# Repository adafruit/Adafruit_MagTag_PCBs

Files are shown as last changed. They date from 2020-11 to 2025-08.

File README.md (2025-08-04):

## Adafruit MagTag PCB

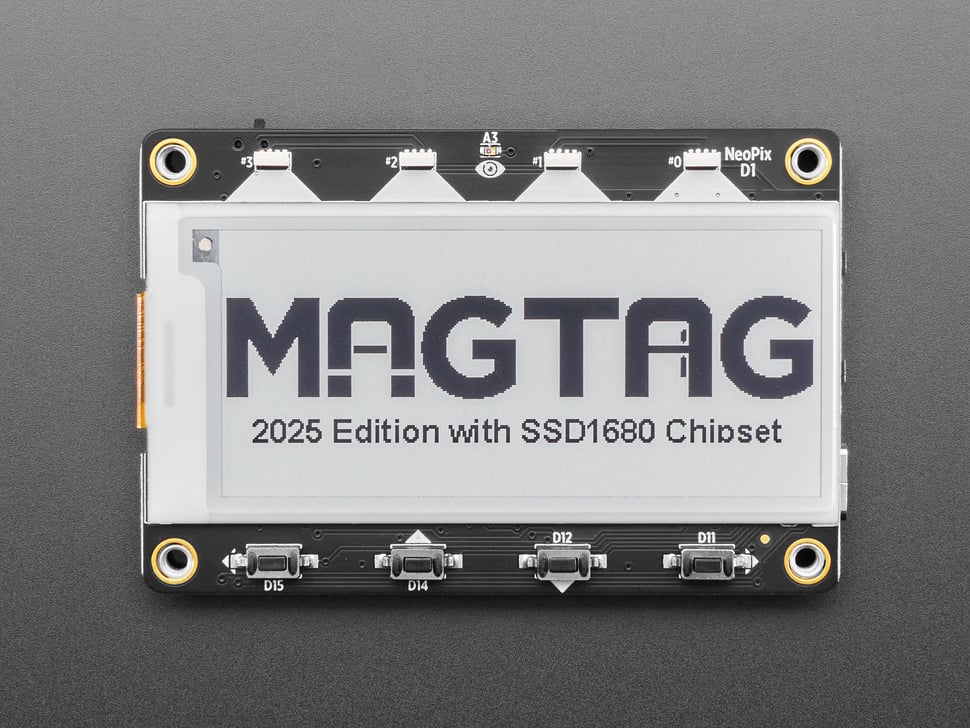
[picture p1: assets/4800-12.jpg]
<a href="http://www.adafruit.com/products/4800"><br/>
Click here to purchase one from the Adafruit shop</a>

PCB files for the Adafruit MagTag.

Format is EagleCAD schematic and board layout
* https://www.adafruit.com/product/4800

### Description

The Adafruit MagTag combines the new ESP32-S2 wireless module and a 2.9" grayscale E-Ink display to make a low-power IoT display that can show data on its screen even when power is removed! The ESP32-S2 is great because it builds on the years of code and support for the ESP32 and also adds native USB support so you can use this board with Arduino or CircuitPython!

New for 2025! After a long break, the MagTag is back in stock, we've found a 2.9" grayscale E-Ink display that replaces the old discontinued ILI0373. The new display has an SSD1680 chip driver and is supported in Arduino and CircuitPython version 10+!

We designed this board to be low-power friendly - with a spot for a 350 or 420 mAh battery and built in battery charging over USB C. During deep sleep, with the NeoPixels and speaker amplifier disabled, we measured 250uA power draw so you can run for a few weeks between charges.

And of course, the Mag in MagTag stands for magnetic. We have four M3 standoffs that will work perfectly with these mini magnet feet. (Originally they're designed for RGB Matrices but they'll do an excellent job here as well). Screw on the feet and you can attach this display to a metallic shelf, fridge, or bench.

Here's the cool hardware we put together:

* ESP32-S2 240MHz Tensilica processor - the next generation of ESP32, now with native USB so it can act like a keyboard/mouse, MIDI device, disk drive, etc!
* WROVER module has FCC/CE certification and comes with 4 MByte of Flash and 2 MByte of PSRAM - you can have huge data buffers
* 2.9" grayscale display with 296x128 pixels. Each pixel can be white, light gray, dark gray or black. Compared to 'tri-color' displays with a red pigment, this display takes a lot less time to update, only about a second instead of 15 seconds!
* USB C power and data connector
* Four RGB side-emitting NeoPixels so you can light up the display with any color or pattern
* Four buttons can be used to wake up the ESP32 from deep-sleep, or select different modes
* Triple-axis accelerometer (LIS3DH) can be used to detect orientation of the display
* Speaker/Buzzer with mini class D amplifier on DAC output A0 can play tones or lo-fi audio clips.
* Front facing light sensor
* STEMMA QT port for attaching all sorts of I2C devices
* Two STEMMA 3 pin JST connectors for attaching NeoPixels, speakers, servos or relays.
* On/Off switch
* Boot and Reset buttons for re-programming

Revision History:

* As of July 22, 2025 – The display has been updated (old one discontinued); it now uses a modern SSD1680 chip instead of the discontinued ILI0373 - we have support in CircuitPython/Python/Arduino for it!
* As of June 17, 2022 - This board may come with a different regulator than AP2112K due to parts shortages. The regulator can provide at least 500mA.
* As of Dec 14, 2020 we're shipping with a different front silkscreen (black not white) Product is otherwise the same

### License

Adafruit invests time and resources providing this open source design, please support Adafruit and open-source hardware by purchasing products from [Adafruit](https://www.adafruit.com)!

Designed by Limor Fried/Ladyada for Adafruit Industries.

Creative Commons Attribution/Share-Alike, all text above must be included in any redistribution.
See license.txt for additional details.

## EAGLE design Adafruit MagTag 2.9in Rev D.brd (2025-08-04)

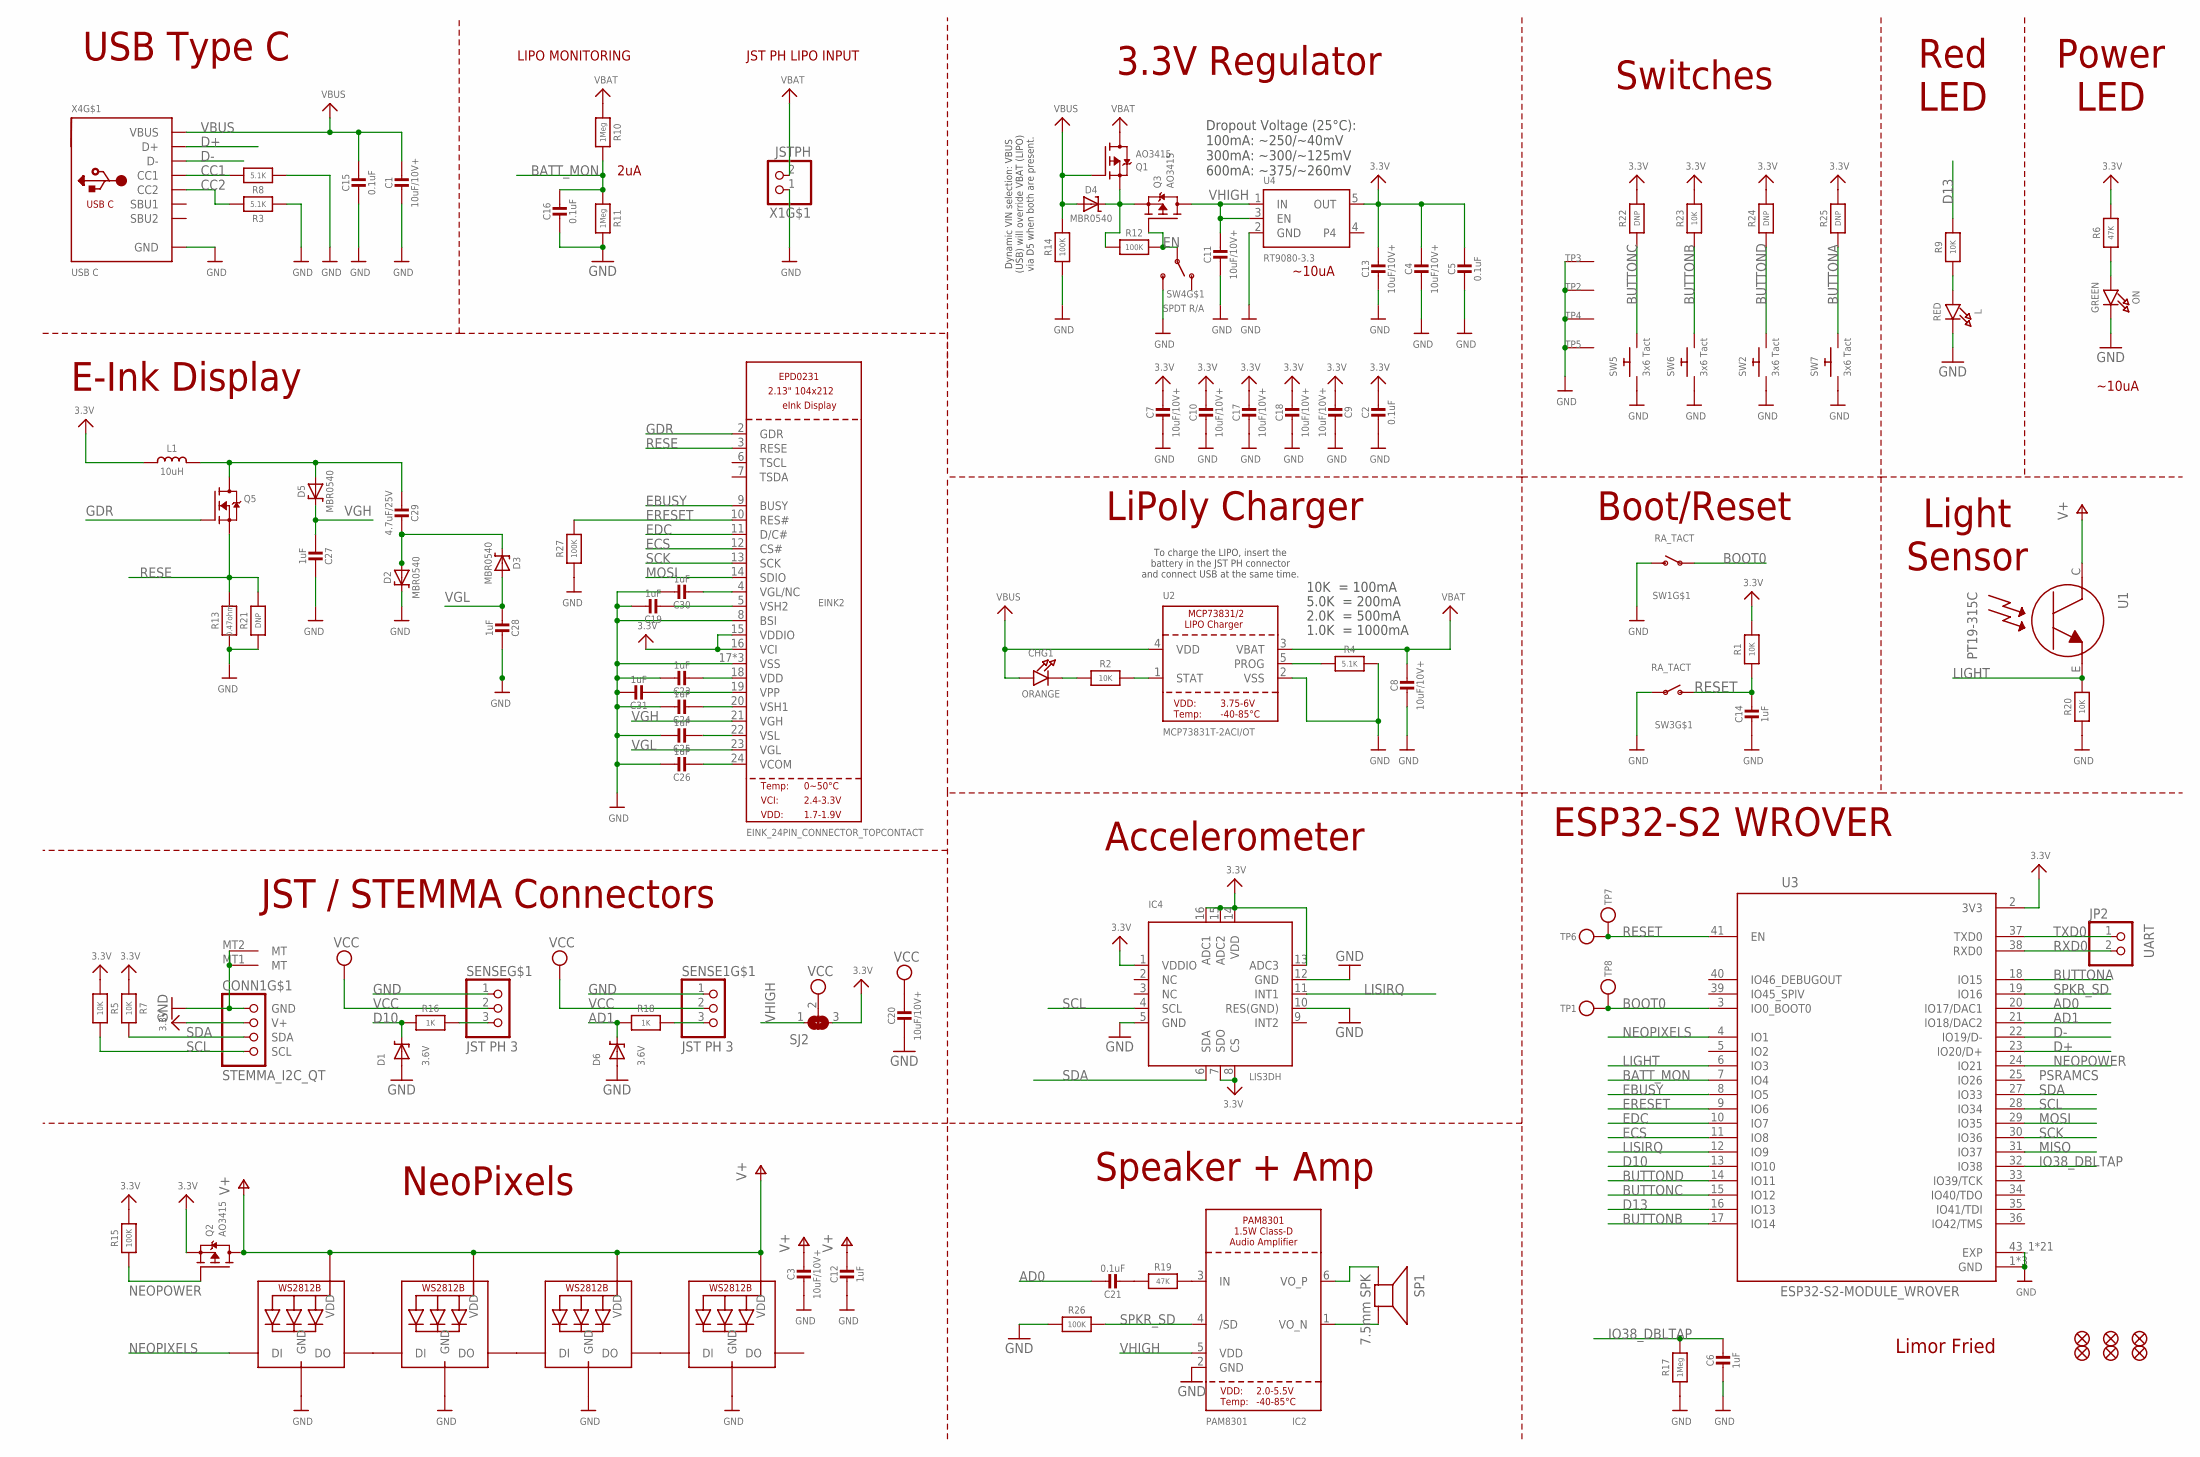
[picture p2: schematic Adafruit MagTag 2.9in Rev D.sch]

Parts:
C1, C3, C4, C7, C8, C9, C10, C11, C13, C17, C18, C20: 10uF/10V+; 0805-NO
C2, C5, C15, C16, C21: 0.1uF; 0603-NO
C6, C12, C14: 1uF; 0603-NO
C19, C23, C24, C25, C26, C27, C28, C30, C31: 1uF; 0805-NO
C29: 4.7uF/25V; 0805-NO
CHG1: ORANGE; CHIPLED_0603_NOOUTLINE
CONN1: STEMMA_I2C_QT; JST_SH4
D1, D6: 3.6V; SOD-323
D2, D3, D4, D5: MBR0540; SOD-123
EINK2: EINK_24PIN_CONNECTOR_TOPCONTACT; EINK_24PIN_TOPCONTACT
FID1, FID2, FID3, FID4, FID5, FID6: FIDUCIAL_1MM
IC2: PAM8301; SOT23-6
IC4: LIS3DH; LGA16_3X3MM
JP2: UART; 1X02_ROUND
L: RED; CHIPLED_0603_NOOUTLINE
L1: 10uH; INDUCTOR_4X4MM_NR401
LED2, LED3, LED4, LED5: WS2812B_4020
ON: GREEN; CHIPLED_0603_NOOUTLINE
Q1, Q2, Q3: AO3415; SOT23-R
Q5: IRLML0100; SOT23-3
R1, R2, R5, R7, R9, R20, R23: 10K; 0603-NO
R3, R4, R8: 5.1K; 0603-NO
R6, R19: 47K; 0603-NO
R10, R11, R17: 1Meg; 0603-NO
R12, R14, R15, R26, R27: 100K; 0603-NO
R13: 0.47ohm; 0805_10MGAP
R16, R18: 1K; 0603-NO
R21: DNP; 0805_10MGAP
R22, R24, R25: DNP; 0603-NO
SENSE, SENSE1: JST PH 3; JSTPH3
SJ2: SOLDERJUMPER_2WAY; SOLDERJUMPER_2WAY_OPEN_NOPASTE
SP1: 7.5mm SPK; BUZZER_SMT_7.5MM
SW1, SW3: RA_TACT; SPST_TACTILE_RA
SW2, SW5, SW6, SW7: 3x6 Tact; TACTILE_3X6MM
SW4: SPDT R/A; SPDT_SMT_SSSS811101
TP1, TP6, TP7, TP8: TESTPOINTROUND1.5MMNO; TESTPOINT_ROUND_1.5MM_NO
TP2, TP3, TP4, TP5: SEWTAP_SMTNUTM3; SMT_NUT_3MM
U1: PT19-315C; ALS-PT19-315C
U2: MCP73831T-2ACI/OT; SOT23-5
U3: ESP32-S2-MODULE_WROVER; MODULE_ESP32-S2-WROVER
U4: RT9080-3.3; SOT23-5; JLC_ROTATION 0
X1: JSTPH; JSTPH2_BATT
X4: USB C; USB_C_CUSB31-CFM2AX-01-X

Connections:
3.3V: C2.1, C4.1, C5.1, C7.1, C9.2, C10.1, C13.1, C17.1, C18.1, CONN1.2 (V+), EINK2.15 (VDDIO), EINK2.16 (VCI), IC4.1 (VDDIO), IC4.7 (SDO), IC4.8 (CS), IC4.13 (ADC3), IC4.14 (VDD), IC4.15 (ADC2), IC4.16 (ADC1), L1.P$2 (2), Q2.2 (S), R1.2, R5.1, R6.2, R7.1, R15.2, R22.2, R23.2, R24.2, R25.2, SJ2.3, U3.2 (3V3), U4.5 (OUT)
A1_JST1: R18.1, SENSE1.3
AD0: C21.1, U3.20 (IO17/DAC1)
AD1: D6.C, R18.2, U3.21 (IO18/DAC2)
BATT_MON: C16.1, R10.2, R11.1, U3.7 (IO4)
BOOT0: SW1.1, TP1.P$1, TP8.P$1, U3.3 (IO0_BOOT0)
BUTTONA: R25.1, SW7.P$2, U3.18 (IO15)
BUTTONB: R23.1, SW6.P$2, U3.17 (IO14)
BUTTONC: R22.1, SW5.P$2, U3.15 (IO12)
BUTTOND: R24.1, SW2.P$2, U3.14 (IO11)
CC1: R8.2, X4.A5 (CC1)
CC2: R3.2, X4.B5 (CC2)
D10: D1.C, R16.2, U3.13 (IO10)
D10_JST: R16.1, SENSE.3
D13: R9.2, U3.16 (IO13)
D+: U3.23 (IO20/D+), X4.A6 (D+), X4.B6 (D+)
D-: U3.22 (IO19/D-), X4.A7 (D-), X4.B7 (D-)
EBUSY: EINK2.9 (BUSY), U3.8 (IO5)
ECS: EINK2.12 (CS#), U3.11 (IO8)
EDC: EINK2.11 (D/C#), U3.10 (IO7)
EN: Q3.1 (G), R12.2, SW4.B
ERESET: EINK2.10 (RES#), R27.2, U3.9 (IO6)
GDR: EINK2.2 (GDR), Q5.1 (G)
GND: C1.2, C2.2, C3.2, C4.2, C5.2, C6.2, C7.2, C8.2, C9.1, C10.2, C11.2, C12.2, C13.2, C14.2, C15.2, C16.2, C17.2, C18.2, C19.1, C20.2, C23.1, C24.1, C25.1, C26.1, C27.2, C28.2, C30.1, C31.1, CONN1.1 (GND), CONN1.MT1 (MT), CONN1.MT2 (MT), D1.A, D2.C, D6.A, EINK2.8 (BSI), EINK2.17 (VSS), EINK2.SPRT1 (VSS), EINK2.SPRT2 (VSS), IC2.2 (GND), IC4.5 (GND), IC4.10 (RES(GND)), IC4.12 (GND), L.C, LED2.4 (GND), LED3.4 (GND), LED4.4 (GND), LED5.4 (GND), ON.C, R3.1, R4.2, R8.1, R11.2, R13.2, R14.1, R17.1, R20.1, R21.2, R26.1, R27.1, SENSE.1, SENSE1.1, SW1.2 (S), SW2.P$1, SW3.1, SW4.C (S), SW5.P$1, SW6.P$1, SW7.P$1, TP2.P$1, TP3.P$1, TP4.P$1, TP5.P$1, U2.2 (VSS), U3.1 (GND), U3.26 (GND), U3.42 (GND), U3.43_1 (EXP), U3.43_2 (EXP), U3.43_3 (EXP), U3.43_4 (EXP), U3.43_5 (EXP), U3.43_6 (EXP), U3.43_7 (EXP), U3.43_8 (EXP), U3.43_9 (EXP), U3.43_10 (EXP), U3.43_11 (EXP), U3.43_12 (EXP), U3.43_13 (EXP), U3.43_14 (EXP), U3.43_15 (EXP), U3.43_16 (EXP), U3.43_17 (EXP), U3.43_18 (EXP), U3.43_19 (EXP), U3.43_20 (EXP), U3.43_21 (EXP), U4.2 (GND), X1.1, X4.A1B12 (GND), X4.B1A12 (GND)
IO38_DBLTAP: C6.1, R17.2, U3.32 (IO38)
LIGHT: R20.2, U1.E, U3.6 (IO3)
LISIRQ: IC4.11 (INT1), U3.12 (IO9)
MISO: U3.31 (IO37)
MOSI: EINK2.14 (SDIO), U3.29 (IO35)
unnamed: L.A, R9.1
unnamed: LED2.3 (DO), LED3.1 (DI)
unnamed: ON.A, R6.1
unnamed: CHG1.C, R2.1
unnamed: C21.2, R19.1
unnamed: R2.2, U2.1 (STAT)
unnamed: IC2.3 (IN), R19.2
unnamed: R4.1, U2.5 (PROG)
unnamed: C19.2, EINK2.5 (VSH2)
unnamed: C23.2, EINK2.18 (VDD)
unnamed: C24.2, EINK2.20 (VSH1)
unnamed: LED4.3 (DO), LED5.1 (DI)
unnamed: C29.2, D2.A, D3.C
unnamed: C29.1, D5.A, L1.P$1 (1), Q5.3 (D)
unnamed: C30.2, EINK2.4 (VGL/NC)
unnamed: C31.2, EINK2.19 (VPP)
unnamed: LED3.3 (DO), LED4.1 (DI)
unnamed: IC2.1 (VO_N), SP1.-
unnamed: IC2.6 (VO_P), SP1.+
unnamed: D4.C, Q1.2 (S), Q3.2 (S), R12.1
unnamed: C25.2, EINK2.22 (VSL)
unnamed: C26.2, EINK2.24 (VCOM)
NEOPIXELS: LED2.1 (DI), U3.4 (IO1)
NEOPOWER: Q2.1 (G), R15.1, U3.24 (IO21)
RESE: EINK2.3 (RESE), Q5.2 (S), R13.1, R21.1
RESET: C14.1, R1.1, SW3.2 (S), TP6.P$1, TP7.P$1, U3.41 (EN)
RXD0: JP2.2, U3.38 (RXD0)
SCK: EINK2.13 (SCK), U3.30 (IO36)
SCL: CONN1.4 (SCL), IC4.4 (SCL), R5.2, U3.28 (IO34)
SDA: CONN1.3 (SDA), IC4.6 (SDA), R7.2, U3.27 (IO33)
SPKR_SD: IC2.4 (/SD), R26.2, U3.19 (IO16)
TXD0: JP2.1, U3.37 (TXD0)
V+: C3.1, C12.1, LED2.2 (VDD), LED3.2 (VDD), LED4.2 (VDD), LED5.2 (VDD), Q2.3 (D), U1.C
VBAT: C8.1, Q1.3 (D), R10.1, U2.3 (VBAT), X1.2
VBUS: C1.1, C15.1, CHG1.A, D4.A, Q1.1 (G), R14.2, U2.4 (VDD), X4.A4B9 (VBUS), X4.B4A9 (VBUS)
VCC: C20.1, SENSE.2, SENSE1.2, SJ2.2
VGH: C27.1, D5.C, EINK2.21 (VGH)
VGL: C28.1, D3.A, EINK2.23 (VGL)
VHIGH: C11.1, IC2.5 (VDD), Q3.3 (D), SJ2.1, U4.1 (IN), U4.3 (EN)

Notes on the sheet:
Limor Fried
10K = 100mA
5.0K = 200mA
2.0K = 500mA
1.0K = 1000mA
LIPO MONITORING
To charge the LIPO, insert the battery in the JST PH connector and connect USB at the same time.
JST PH LIPO INPUT
Dynamic VIN selection: VBUS (USB) will override VBAT (LIPO) via D5 when both are present.
Dropout Voltage (25°C): 100mA: ~250/~40mV 300mA: ~300/~125mV 600mA: ~375/~260mV
PSRAMCS
2uA
~10uA
E-Ink Display
LiPoly Charger
Accelerometer
Speaker + Amp
3.3V Regulator
ESP32-S2 WROVER
Switches
Boot/Reset
USB Type C
Light Sensor
Red LED
Power LED
NeoPixels
JST / STEMMA Connectors

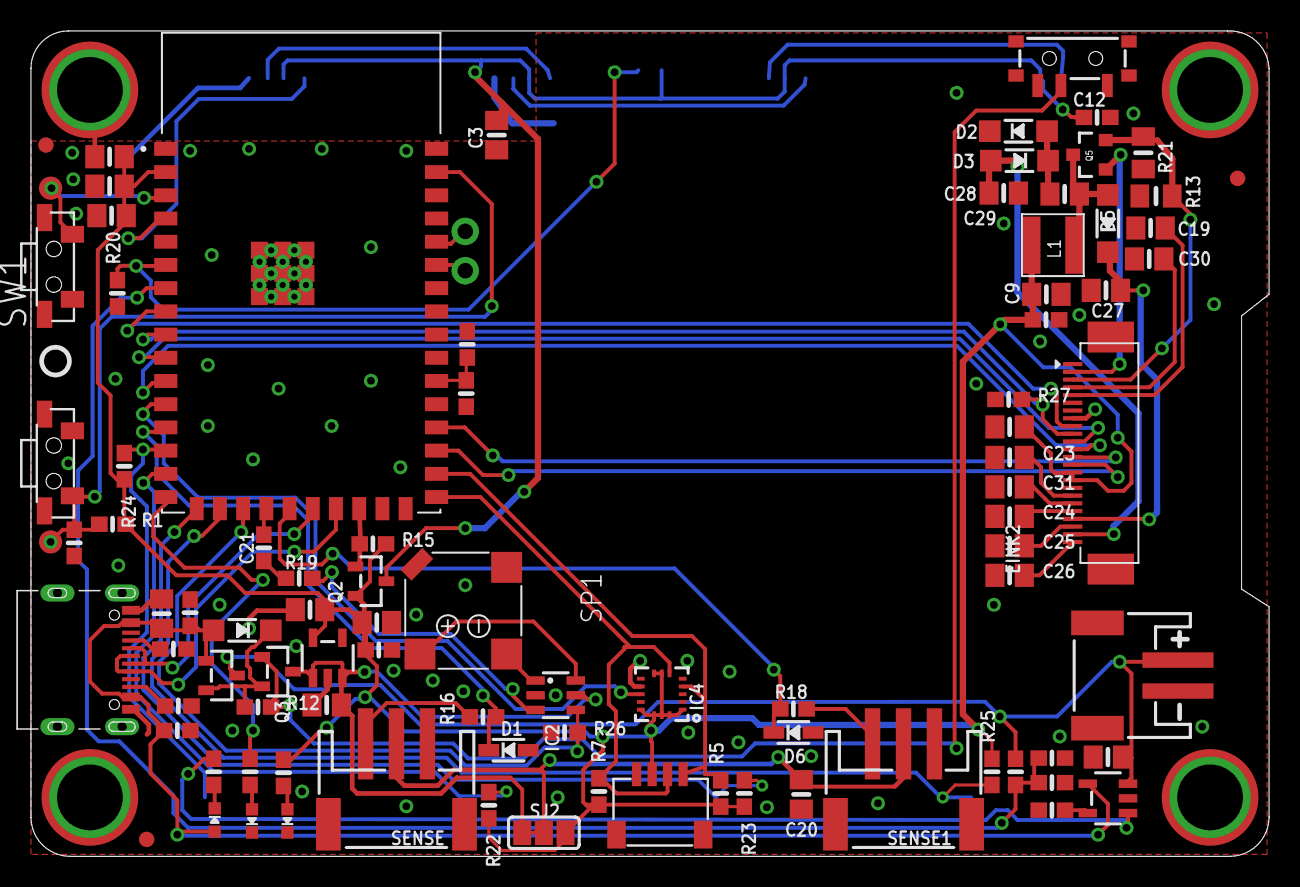
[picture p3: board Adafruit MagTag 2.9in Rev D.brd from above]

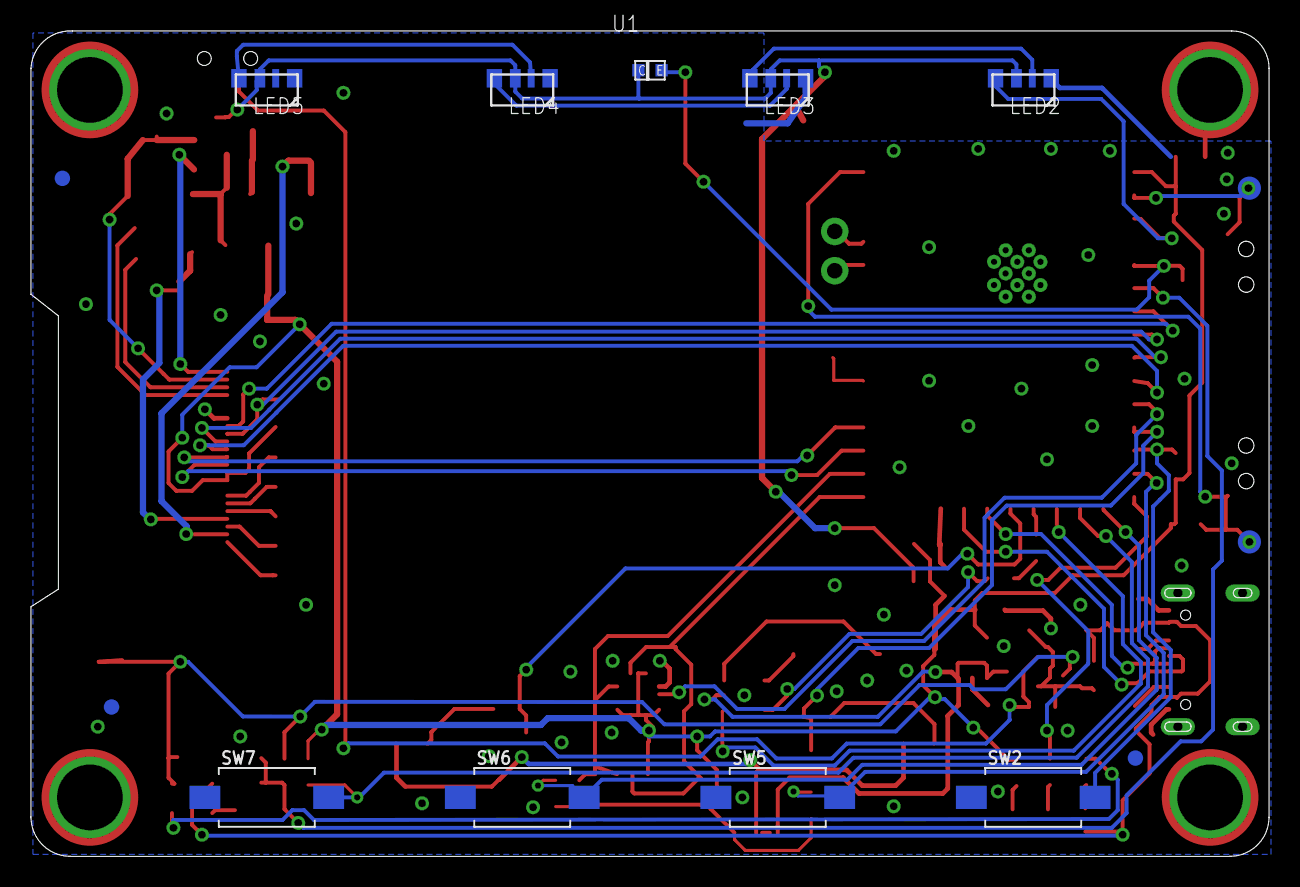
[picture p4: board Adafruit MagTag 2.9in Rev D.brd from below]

Board: 2 copper layers, 80.0 x 53.3 mm, 114 parts (15 on the bottom side), 67 nets.

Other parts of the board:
U$15: PCBFEAT-REV-040
U$69: MAGTAG_BOTTOM
U$70: MAGTAG_FRONT

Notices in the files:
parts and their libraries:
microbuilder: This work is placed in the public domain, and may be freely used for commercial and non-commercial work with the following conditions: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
